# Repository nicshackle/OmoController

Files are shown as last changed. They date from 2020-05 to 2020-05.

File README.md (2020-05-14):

# OmoController
###### A wearable game controller that tracks scalar hand motion

The omo controller was designed to be embedded in the cuff of a boxing glove. When a punch is thrown, the unit transmits that event to a receiver, which was connected to a bespoke computer game. 

The unit has headers for an Xbee radio, which it would use to transmit data.

The controller measures 4x3x1.5cm, including 500mAh LiPo battery. The unit has charging circuitry on-board, which allows for charging from USB power.

The below controller travelled around South Africa as part of a promotional installation. 

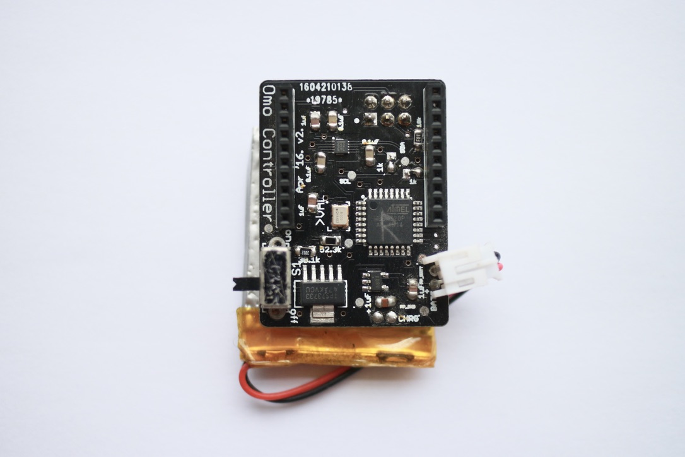
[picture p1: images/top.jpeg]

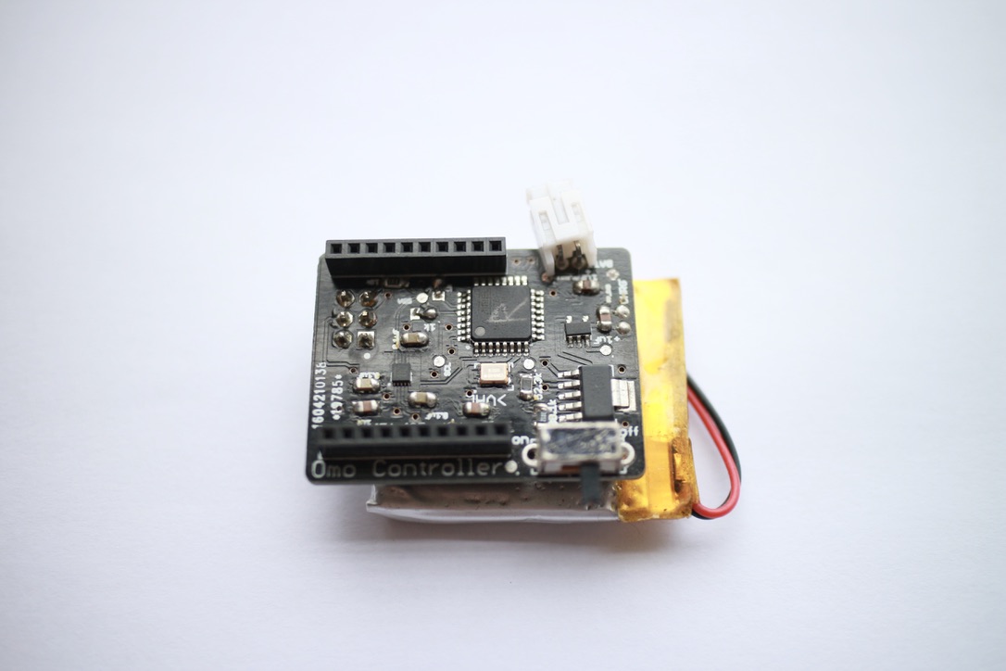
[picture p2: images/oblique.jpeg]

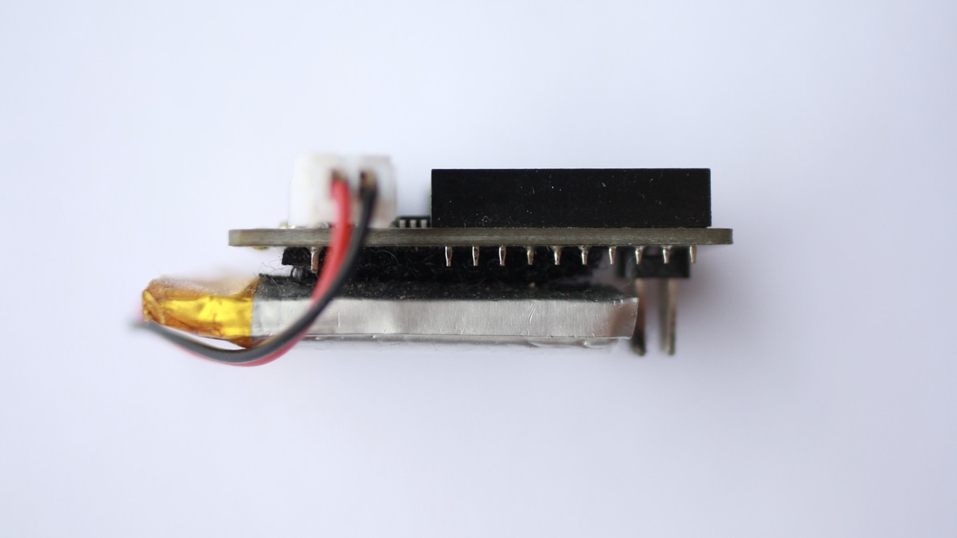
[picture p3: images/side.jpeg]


## Schematic

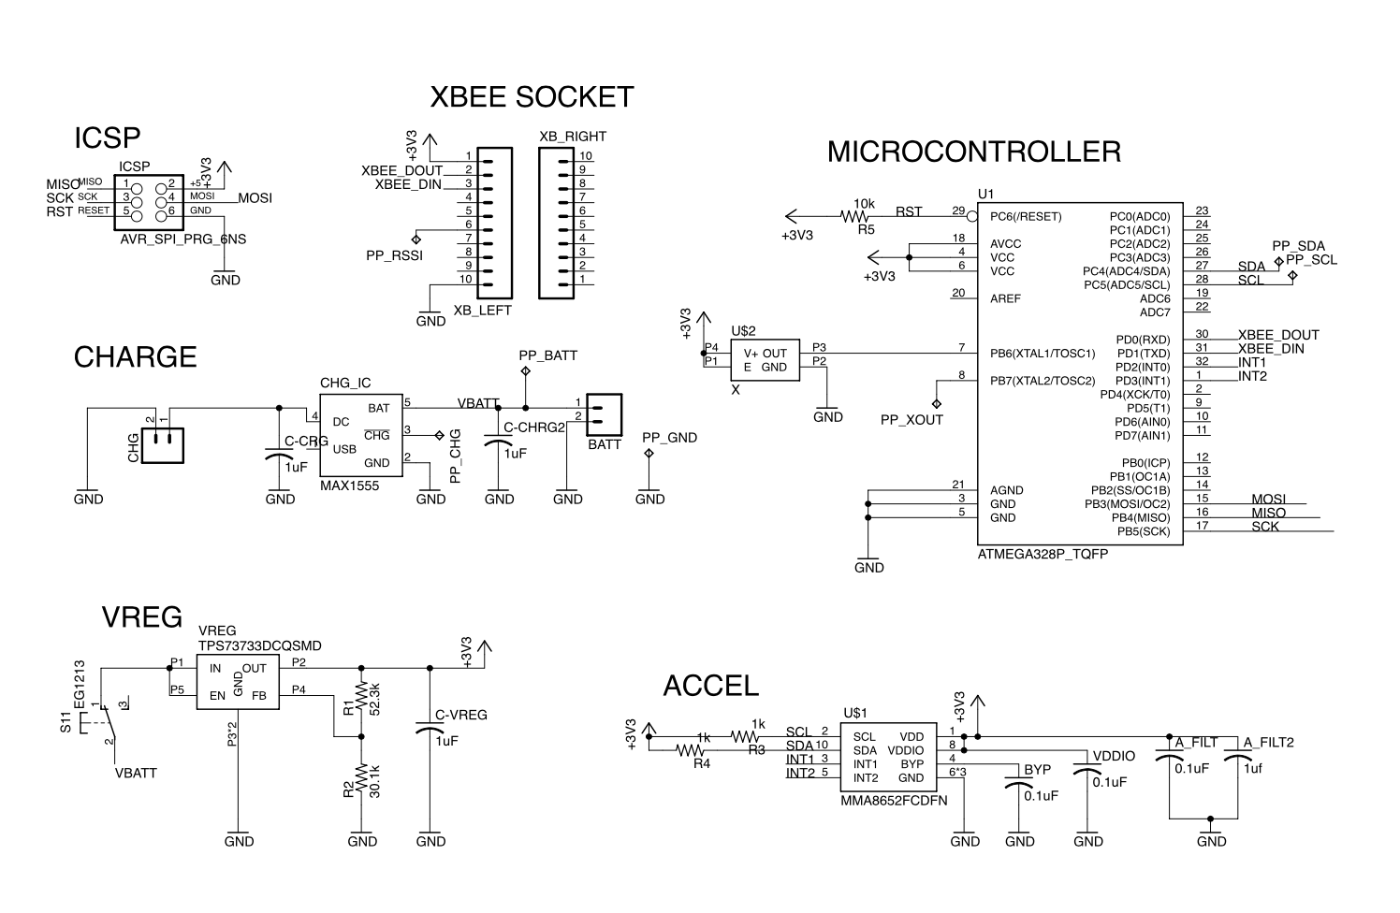
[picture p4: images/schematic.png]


## Parts

|Part|Name|
|:---|:---|
|Microcontroller|Atmel 328P, 3.3V, 8MHz|
|Accelerometer|NXP MMA8652FC|
|Charge controller|MAX1555|
|LDO Voltage Regulator|TI TPS73733†|

†This part has a dropout of 130mV, i.e. it will drop out at 3.43V. This voltage is very near the total depletion point of LiPo batteries, which means the device is able to make use of most of the battery's charge. 

## Programming

 - Use 3.3v ICSP programmer
 - If using a fresh chip, burn the Arduino 3.3V 8MHz bootloader to set fuse bits

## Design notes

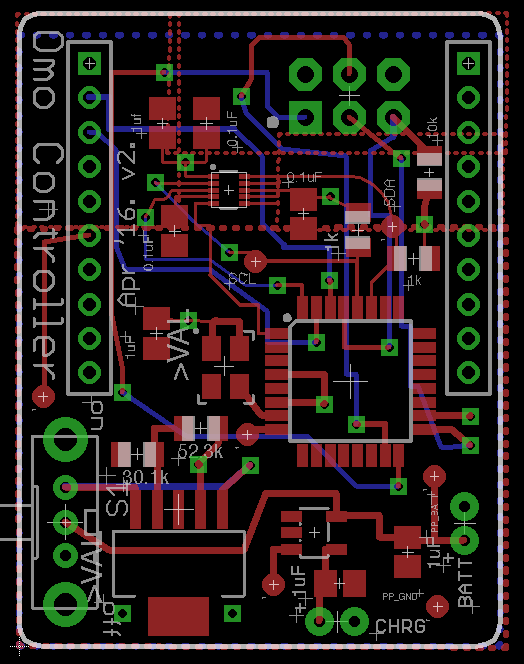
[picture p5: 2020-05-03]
images/boardSnapshot.png

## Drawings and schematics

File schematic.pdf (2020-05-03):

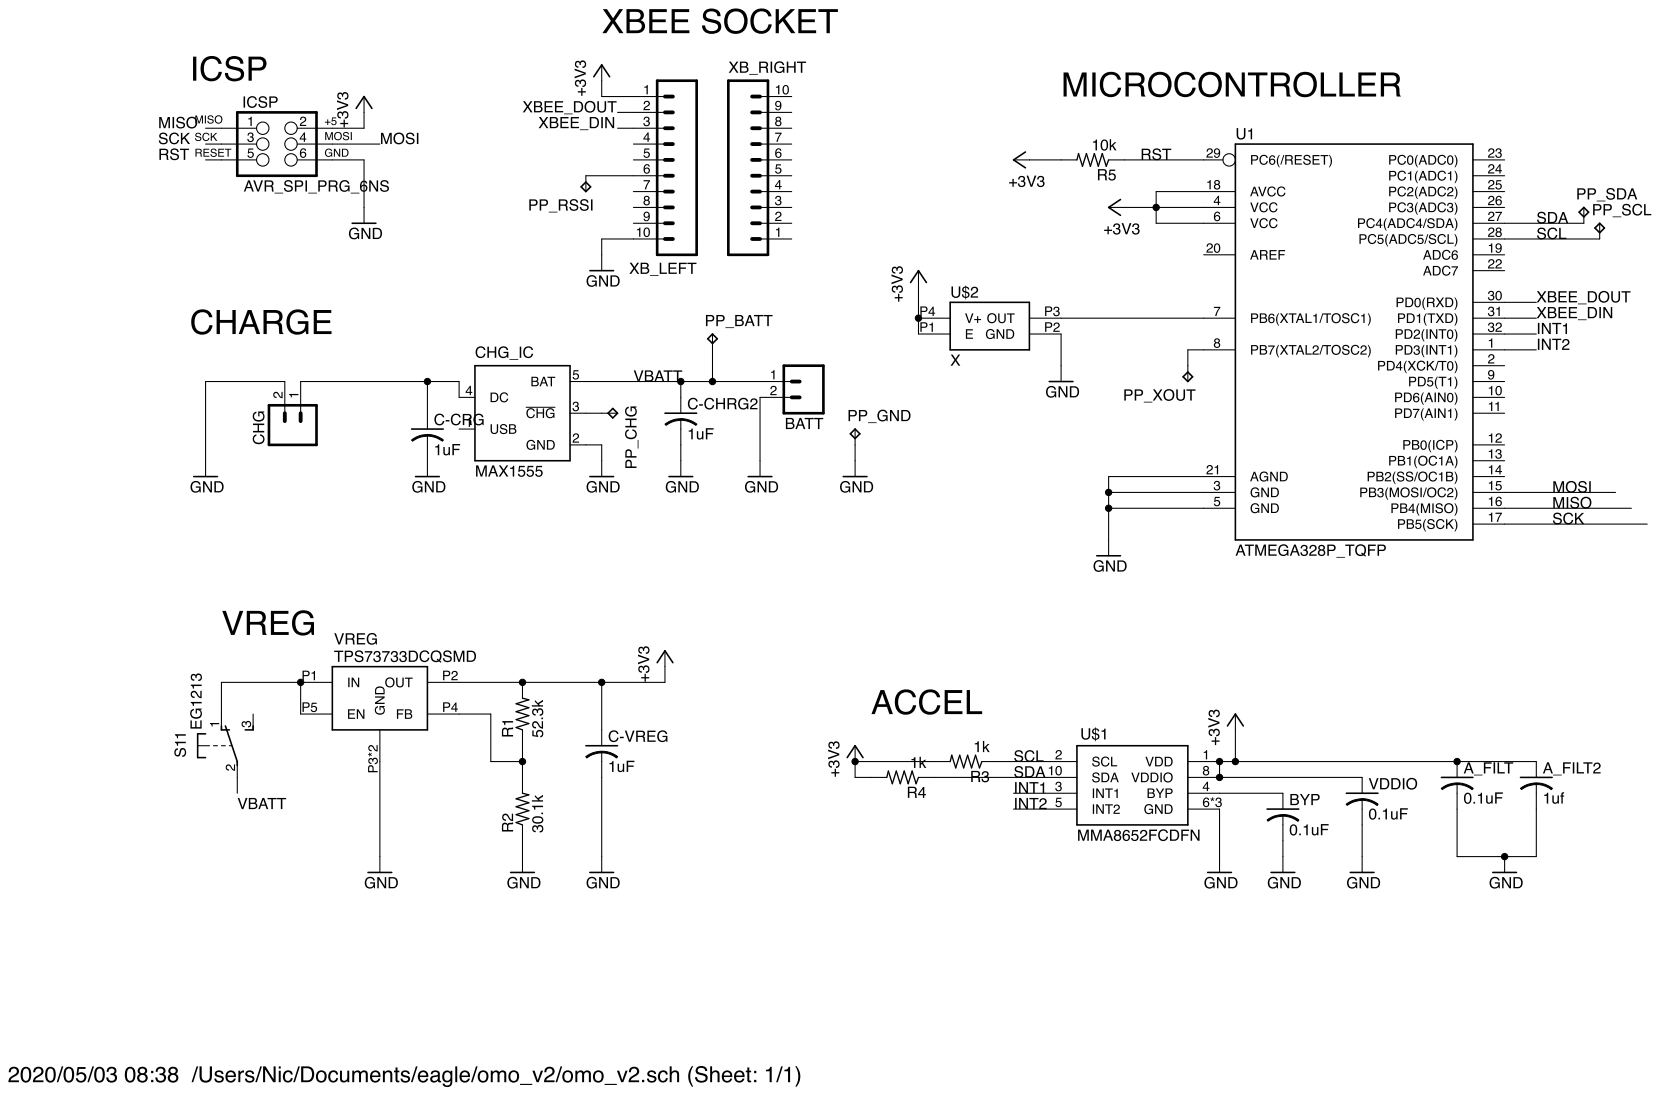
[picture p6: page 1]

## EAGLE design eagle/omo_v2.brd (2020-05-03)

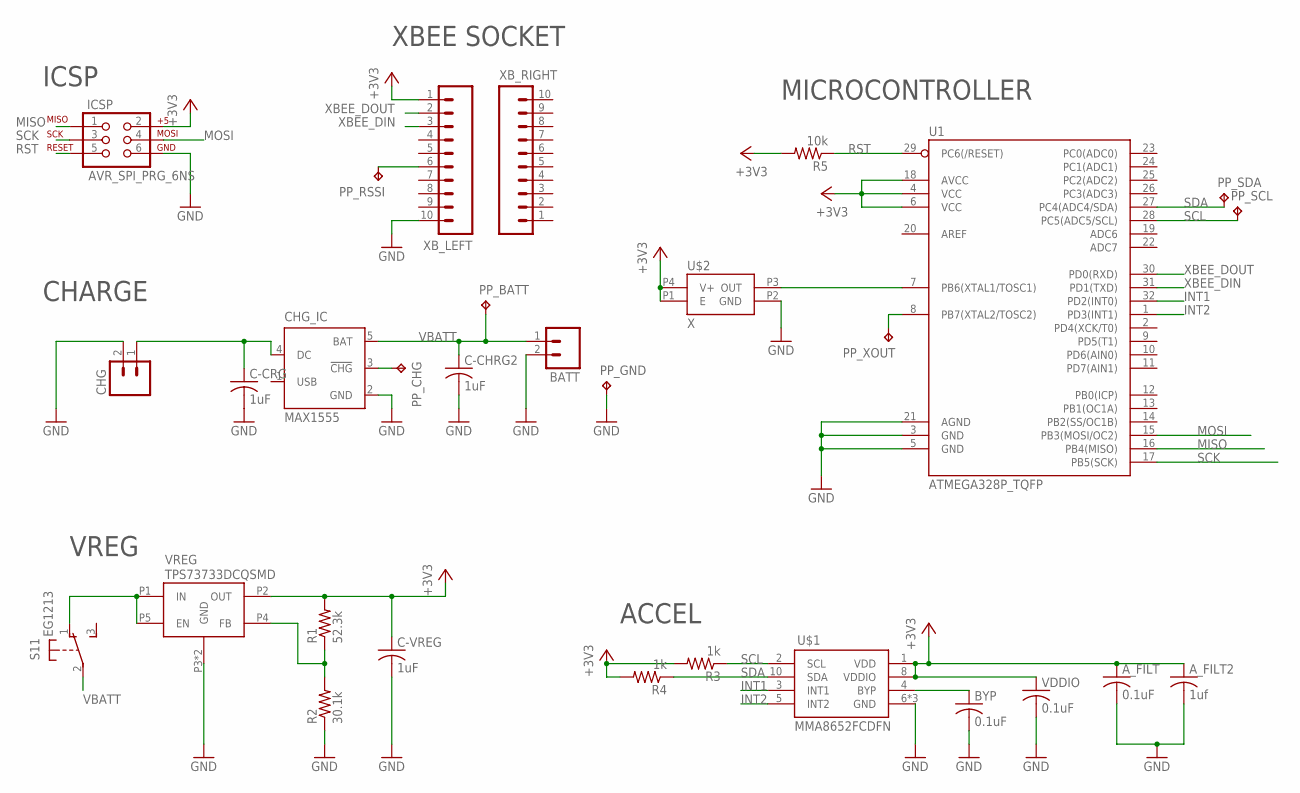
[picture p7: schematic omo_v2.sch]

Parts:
A_FILT: 0.1uF; C0805
A_FILT2: 1uf; C0805
BATT: M02-JST-2-PTH-NO_SILK; JST-2-PTH-NS
BYP: 0.1uF; C0805
C-CHRG2: 1uF; C0805
C-CRG: 1uF; C0805
C-VREG: 1uF; C0805
CHG: M02-JST-2-PTH-NO_SILK; JST-2-PTH-NS
CHG_IC: MAX1555; SOT23-5L
ICSP: AVR_SPI_PRG_6NS; 2X3-NS
PP_BATT: TPB1,27; B1,27
PP_CHG: TPB1,27; B1,27
PP_GND: TPB1,27; B1,27
PP_RSSI: TPB1,27; B1,27
PP_SCL: TPB1,27; B1,27
PP_SDA: TPB1,27; B1,27
PP_XOUT: TPB1,27; B1,27
R1: 52.3k; R0805
R2: 30.1k; R0805
R3, R4: 1k; R0805
R5: 10k; R0805
S1: EG1213
U1: ATMEGA328P_TQFP; TQFP32-08
U$1: MMA8652FCDFN; MMA8652FC
U$2: X; QX3-OSC-3.2X2.5
VDDIO: 0.1uF; C0805
VREG: TPS73733DCQSMD; SOT-223-6
XB_LEFT: M102MM; 1X10-2MM
XB_RIGHT: M102MM; 1X10-2MM

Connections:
+3V3: A_FILT.1, A_FILT2.1, C-VREG.1, ICSP.2, R1.2, R3.2, R4.2, R5.2, U1.4 (VCC), U1.6 (VCC), U1.18 (AVCC), U$1.1 (VDD), U$1.8 (VDDIO), U$2.P1 (E), U$2.P4 (V+), VDDIO.1, VREG.P2 (OUT), XB_LEFT.1
GND: A_FILT.2, A_FILT2.2, BATT.2, BYP.2, C-CHRG2.2, C-CRG.2, C-VREG.2, CHG.2, CHG_IC.2 (GND), ICSP.6, PP_GND.TP, R2.1, U1.3 (GND), U1.5 (GND), U1.21 (AGND), U$1.6 (GND), U$1.7 (GND), U$1.9 (GND), U$2.P2 (GND), VDDIO.2, VREG.P3 (GND), VREG.P6 (GND), XB_LEFT.10
INT1: U1.32 (PD2(INT0)), U$1.3 (INT1)
INT2: U1.1 (PD3(INT1)), U$1.5 (INT2)
MISO: ICSP.1, U1.16 (PB4(MISO))
MOSI: ICSP.4, U1.15 (PB3(MOSI/OC2))
unnamed: CHG_IC.3 (!CHG), PP_CHG.TP
unnamed: PP_RSSI.TP, XB_LEFT.6
unnamed: R1.1, R2.2, VREG.P4 (FB)
unnamed: S1.1 (O), VREG.P1 (IN), VREG.P5 (EN)
unnamed: PP_XOUT.TP, U1.8 (PB7(XTAL2/TOSC2))
unnamed: U1.7 (PB6(XTAL1/TOSC1)), U$2.P3 (OUT)
unnamed: BYP.1, U$1.4 (BYP)
RST: ICSP.5, R5.1, U1.29 (PC6(/RESET))
SCK: ICSP.3, U1.17 (PB5(SCK))
SCL: PP_SCL.TP, R3.1, U1.28 (PC5(ADC5/SCL)), U$1.2 (SCL)
SDA: PP_SDA.TP, R4.1, U1.27 (PC4(ADC4/SDA)), U$1.10 (SDA)
VBATT: BATT.1, C-CHRG2.1, CHG_IC.5 (BAT), PP_BATT.TP, S1.2
VUSB: C-CRG.1, CHG.1, CHG_IC.4 (DC)
XBEE_DIN: U1.31 (PD1(TXD)), XB_LEFT.3
XBEE_DOUT: U1.30 (PD0(RXD)), XB_LEFT.2

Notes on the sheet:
VREG
CHARGE
ACCEL
ICSP
XBEE SOCKET
MICROCONTROLLER

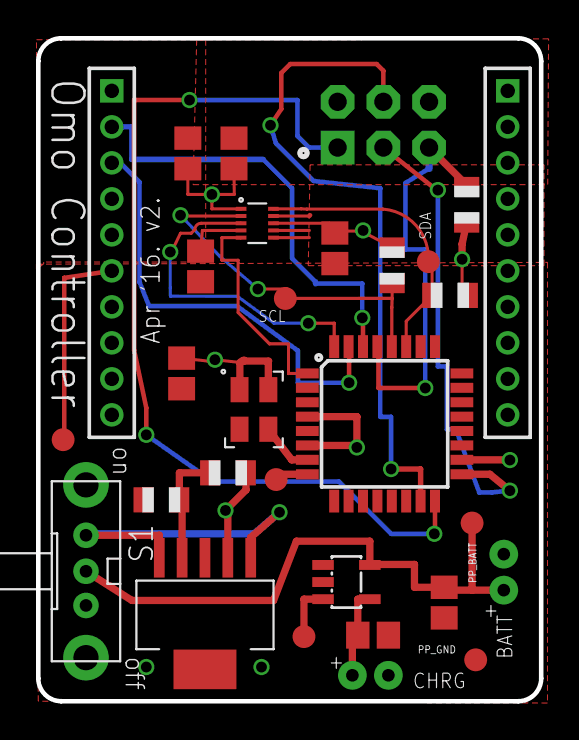
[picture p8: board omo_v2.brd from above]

Board: 2 copper layers, 27.9 x 36.8 mm, 30 parts (0 on the bottom side), 21 nets.

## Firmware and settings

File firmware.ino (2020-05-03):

#define LEFTHAND
//#define RIGHTHAND

#include <Wire.h>

// I2C BUS:  already defined in "wire" librairy
// SDA: PIN 2 with pull up 4.7K to 3.3V on arduino Micro
// SCL: PIN 3 with pull up 4.7K to 3.3V on arduino Micro
// Accelerometer connected to +3.3V of arduino DO NOT CONNECT TO 5V (this will destroy the accelerometer!)
// all GND Pin of accelerometer connected to gnd of arduino

/********************ACCELEROMETER DATAS************/
// adresss of accelerometer
int adress_acc = 0X1D; // MMA8653FC and MMA8652FC
// adress of registers for MMA8653FC
int ctrl_reg1 = 0x2A;
int ctrl_reg2 = 0x2B;
int ctrl_reg3 = 0x2C;
int ctrl_reg4 = 0x2D;
int ctrl_reg5 = 0x2E;
int int_source = 0x0C;
int status_ = 0x00;
int f_setup = 0x09;
int out_x_msb = 0x01;
int out_y_msb = 0x03;
int out_z_msb = 0x05;
int sysmod = 0x0B;
int xyz_data_cfg = 0x0E;
int HPF_cutoff = 0x0F;

/******PROGRAM DATAS**********/
int result [3];
int axeXnow ;
int axeYnow ;
int axeZnow ;


void setup() {
  Wire.begin(); // start of the i2c protocol
  Serial.begin(115200);  // start serial for output
  ACC_INIT(); // initialize the accelerometer by the i2c bus. enter the sub to adjust the range (2g, 4g, 8g), and the data rate (800hz to 1,5Hz)
}

//------------------------------------------------------------------

void loop()
{
  I2C_READ_ACC(0x00); // to understand why 0x00 and not 0x01, look at the data-sheet p.19 or on the comments of the sub. This is valid only becaus we use auto-increment
  // NOTE: This communication is taking a little less than 1ms to be done. (for data-rate calculation for delay)


  float xf = float(axeXnow);
  float yf = float(axeYnow);
  float zf = float(axeZnow);

  int magnitude = (int)sqrt((xf * xf) + (yf * yf) + (zf * zf));

  if (magnitude > 150) { //average max is 300, so let's go half way
#ifdef LEFTHAND
    Serial.print('L');
#endif
#ifdef RIGHTHAND
    Serial.print('R');
#endif
  }

  delay(2); //at on ODR of 800Hz, min delay would be 1.25ms
}

//------------------------------------------------------------------

void ACC_INIT()
{
  I2C_SEND(ctrl_reg1 , 0X00); // standby to be able to configure
  delay(10);

  // I2C_SEND(xyz_data_cfg ,B00000000); // 2G full range mode
  // delay(1);
  //   I2C_SEND(xyz_data_cfg ,B00000001); // 4G full range mode
  //   delay(1);
  I2C_SEND(xyz_data_cfg , B00010010); // 8G full range mode //was B00000010
  delay(1);
  I2C_SEND(HPF_cutoff , B00000011); // set highpass cutoff to 2hz @800Hz ODR, normal oversampling (pg33 datasheet)
  delay(1);

  I2C_SEND(ctrl_reg1 , B00000001); // Output data rate at 800Hz, no auto wake, no auto scale adjust, no fast read mode
  delay(1);
  //   I2C_SEND(ctrl_reg1 ,B00100001); // Output data rate at 200Hz, no auto wake, no auto scale adjust, no fast read mode
  //   delay(1);
  //   I2C_SEND(ctrl_reg1 ,B01000001); // Output data rate at 50Hz, no auto wake, no auto scale adjust, no fast read mode
  //   delay(1);
  //   I2C_SEND(ctrl_reg1 ,B01110001); // Output data rate at 1.5Hz, no auto wake, no auto scale adjust, no fast read mode
  //   delay(1);
}

//------------------------------------------------------------------

void I2C_SEND(unsigned char REG_ADDRESS, unsigned  char DATA)  //SEND data to MMA7660
{

  Wire.beginTransmission(adress_acc);
  Wire.write(REG_ADDRESS);
  Wire.write(DATA);
  Wire.endTransmission();
}

//------------------------------------------------------------------

void I2C_READ_ACC(int ctrlreg_address) //READ number data from i2c slave ctrl-reg register and return the result in a vector
{
  byte REG_ADDRESS[7];
  int accel[4];
  int i = 0;
  Wire.beginTransmission(adress_acc); //=ST + (Device Adress+W(0)) + wait for ACK
  Wire.write(ctrlreg_address);  // store the register to read in the buffer of the wire library
  Wire.endTransmission(); // actually send the data on the bus -note: returns 0 if transmission OK-
  Wire.requestFrom(adress_acc, 7); // read a number of byte and store them in wire.read (note: by nature, this is called an "auto-increment register adress")

  for (i = 0; i < 7; i++) // 7 because on datasheet p.19 if FREAD=0, on auto-increment, the adress is shifted
    // according to the datasheet, because it's shifted, outZlsb are in adress 0x00
    // so we start reading from 0x00, forget the 0x01 which is now "status" and make the adapation by ourselves
    //this gives:
    //0 = status
    //1= X_MSB
    //2= X_LSB
    //3= Y_MSB
    //4= Y_LSB
    //5= Z_MSB
    // 6= Z_LSB
  {
    REG_ADDRESS[i] = Wire.read(); //each time you read the write.read it gives you the next byte stored. The couter is reset on requestForm
  }


  // MMA8653FC gives the answer on 10bits. 8bits are on _MSB, and 2 are on _LSB
  // this part is used to concatenate both, and then put a sign on it (the most significant bit is giving the sign)
  // the explanations are on p.14 of the 'application notes' given by freescale.
  for (i = 1; i < 7; i = i + 2)
  {
    accel[0] = (REG_ADDRESS[i + 1] | ((int)REG_ADDRESS[i] << 8)) >> 6; // X
    if (accel[0] > 0x01FF) {
      accel[1] = (((~accel[0]) + 1) - 0xFC00); // note: with signed int, this code is optional
    }
    else {
      accel[1] = accel[0]; // note: with signed int, this code is optional
    }
    switch (i) {
      case 1: axeXnow = accel[1];
        break;
      case 3: axeYnow = accel[1];
        break;
      case 5: axeZnow = accel[1];
        break;
    }
  }

}

//------------------------------------------------------------------

void I2C_READ_REG(int ctrlreg_address) //READ number data from i2c slave ctrl-reg register and return the result in a vector
{
  unsigned char REG_ADDRESS;
  int i = 0;
  Wire.beginTransmission(adress_acc); //=ST + (Device Adress+W(0)) + wait for ACK
  Wire.write(ctrlreg_address);  // register to read
  Wire.endTransmission();
  Wire.requestFrom(adress_acc, 1); // read a number of byte and store them in write received
}

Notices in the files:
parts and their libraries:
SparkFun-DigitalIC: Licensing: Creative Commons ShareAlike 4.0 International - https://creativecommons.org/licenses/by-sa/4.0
